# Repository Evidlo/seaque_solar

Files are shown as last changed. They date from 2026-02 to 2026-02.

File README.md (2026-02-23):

# seaque_solar

Design files for [SEAQUE](https://research.physics.illinois.edu/QI/Photonics/SEAQUE/) solar experiment.

# Files

- `board/` - KiCAD design files for IV sweeper
- `firmware/` - STM32 software for downlinking through SEAQUE
- `analysis/` - post-downlink analysis software

# Pics

Integrated experiment

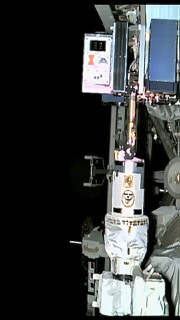
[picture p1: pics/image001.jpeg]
On-board the ISS






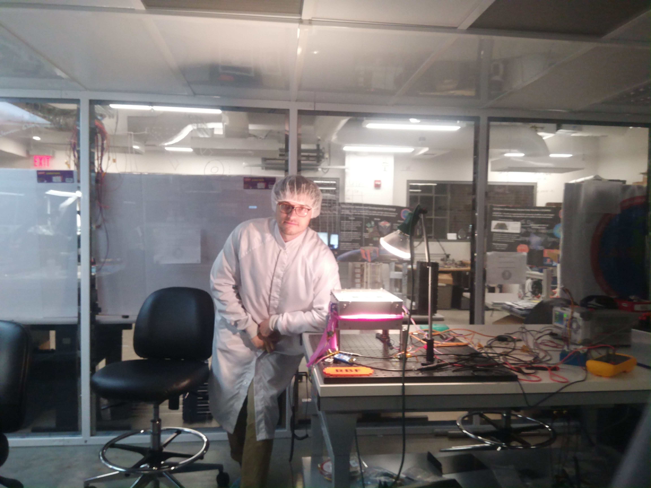
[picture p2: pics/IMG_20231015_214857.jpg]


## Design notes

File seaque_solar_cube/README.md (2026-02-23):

# SEAQUE QCB Firmware
This repo has the firmware for the SEAQUE Quantum Control Board, which controls a majority of experiment functions. It was originally an STM32CubeIDE project, but is now buildable with CMake via the `build.sh` script.

## How to Build
These instructions assume you are using a unix-like environment, like Linux, MacOS, or WSL. Fist make sure to install the GNU Arm Embedded Toolchain, as well as CMake. With these, the script `build.sh` should run without issue.

## How to Program/Debug
Install openocd, and in the main directory of the repo, run the command `openocd`. It should pick up the `openocd.cfg` file. There is also a `.gdbinit` file that connects to the openocd server, sets a source layout, and grabs symbols from the right file. To start debugging, simply run `arm-none-eabi-gdb`. To program the board, run the gdb command `load`.

target extended-remote :3333
lay src
focus cmd

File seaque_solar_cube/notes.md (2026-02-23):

# Programming

    ./build.sh && sh /home/evan/.arduino15/packages/STMicroelectronics/tools/STM32Tools/2.1.1/stm32CubeProg.sh 0 build/qcb.elf -g
	
# Debugging

program with gdb:
	load build/elf

connect with:
openocd

$ arm-none-eabi-gdb example.elf
then:
	target extended-remote localhost:3333

file build/qcb.elf
target extended-remote 10.195.192.196:3341
load

lay src
# reset and halt
mon reset halt
b main
c

b main
b [lineno]

# save to file
(gdb) set logging file large_array.txt
(gdb) set logging on
p packet_data[0]@3072

dump binary memory out.bin &packet_data[0] &packet_data[3072]

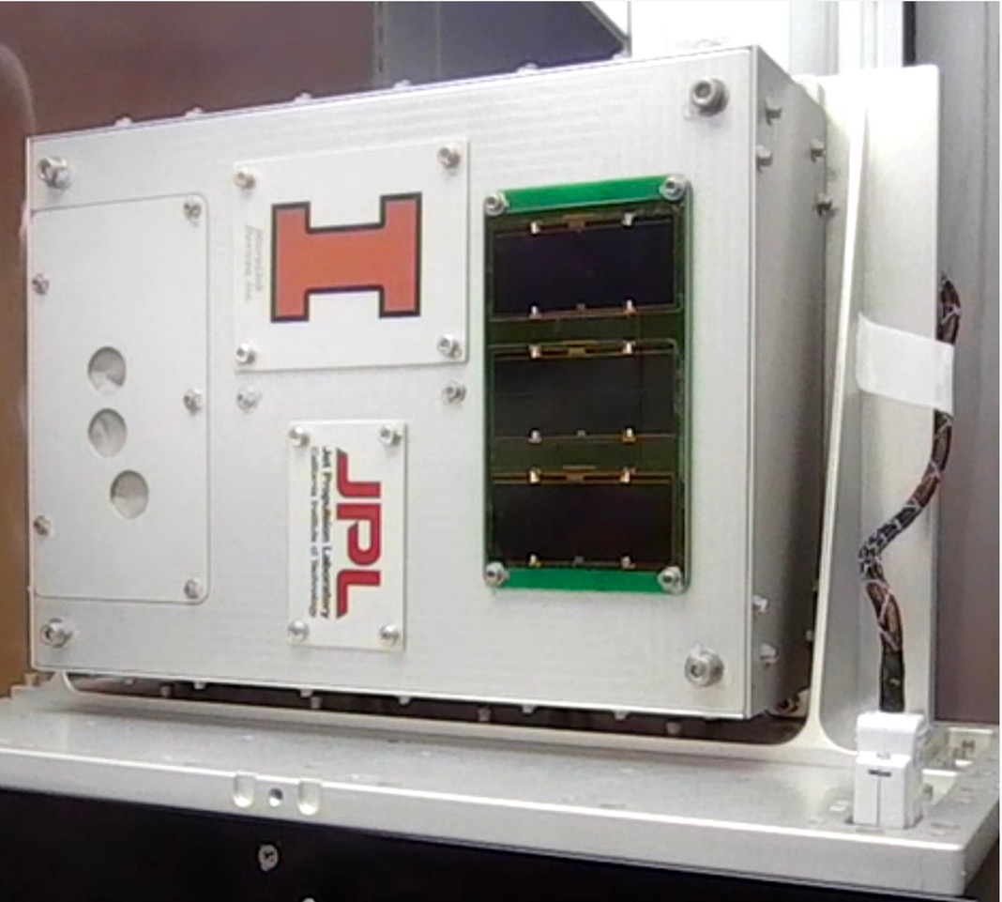
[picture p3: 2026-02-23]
pics/integration pic.jpeg

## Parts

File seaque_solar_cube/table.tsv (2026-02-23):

id | type | is_array | shape | readable | writeable | executable | read_cb | write_cb | exec_func | initial_value | include | comments
telemetry_en | bool | FALSE |  | TRUE | TRUE | FALSE |  |  |  | FALSE |  | Enable telemetry

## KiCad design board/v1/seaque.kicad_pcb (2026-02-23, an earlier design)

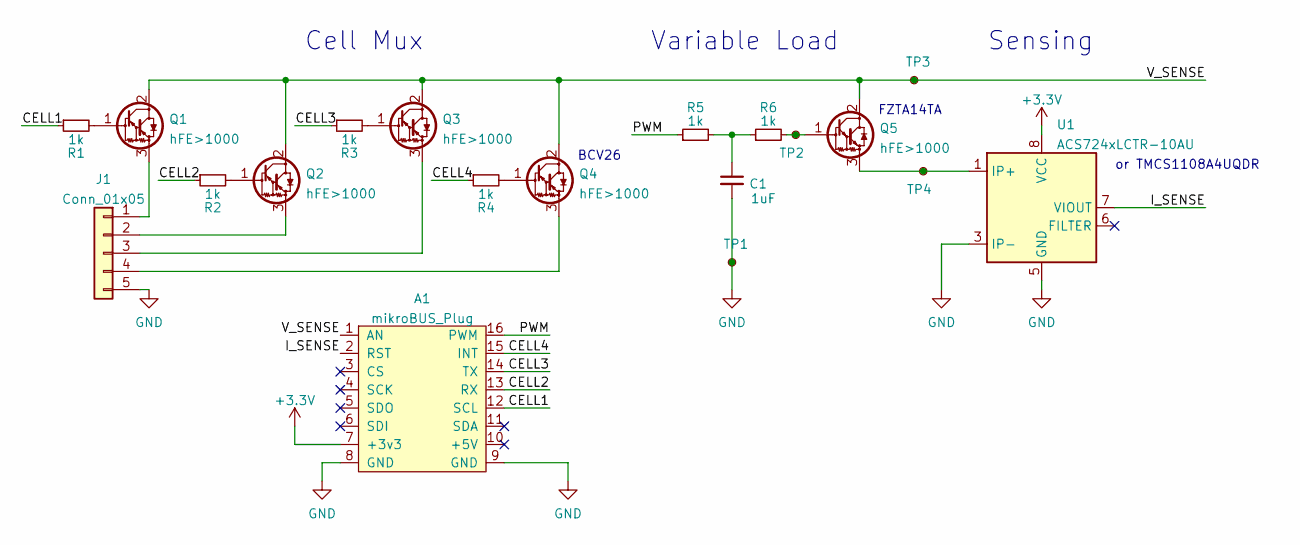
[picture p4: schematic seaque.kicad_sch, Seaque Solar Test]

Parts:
A1: mikroBUS_Plug
C1: 1uF; C_0603_1608Metric
J1: Conn_01x05; Molex_Pico-Lock_504050-0591_1x05-1MP_P1.50mm_Horizontal
Q1, Q2, Q3, Q4: hFE>1000; SC-59_Handsoldering
Q5: hFE>1000; SOT-223-3_TabPin2
R1, R2, R3, R4, R5, R6: 1k; R_0603_1608Metric
TP1, TP2, TP3, TP4: TestPoint_Small; TestPoint_Loop_D2.50mm_Drill1.0mm
U1: ACS724xLCTR-10AU; SOIC-8_3.9x4.9mm_P1.27mm

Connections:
+3V3: A1.7 (+3v3), U1.8 (VCC)
/CELL1: A1.12 (SCL), R1.1
/CELL2: A1.13 (RX), R2.1
/CELL3: A1.14 (TX), R3.1
/CELL4: A1.15 (INT), R4.1
/I_SENSE: A1.2 (RST), U1.7 (VIOUT)
/PWM: A1.16 (PWM), R5.1
/V_SENSE: A1.1 (AN), Q1.2 (C), Q2.2 (C), Q3.2 (C), Q4.2 (C), Q5.2 (C), TP3.1
GND: A1.8 (GND), A1.9 (GND), C1.2, J1.5, TP1.1, U1.3 (IP-), U1.4 (IP-), U1.5 (GND)
unnamed: C1.1, R5.2, R6.1
unnamed: J1.1, Q1.3 (E)
unnamed: J1.2, Q2.3 (E)
unnamed: J1.3, Q3.3 (E)
unnamed: J1.4, Q4.3 (E)
unnamed: Q1.1 (B), R1.2
unnamed: Q2.1 (B), R2.2
unnamed: Q3.1 (B), R3.2
unnamed: Q4.1 (B), R4.2
unnamed: Q5.1 (B), R6.2, TP2.1
unnamed: Q5.3 (E), TP4.1, U1.1 (IP+), U1.2 (IP+)

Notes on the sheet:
Cell Mux
or TMCS1108A4UQDR
Variable Load
BCV26
FZTA14TA
Sensing

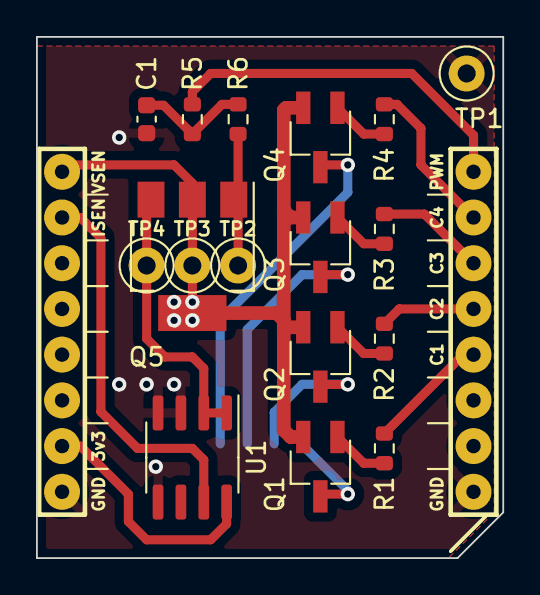
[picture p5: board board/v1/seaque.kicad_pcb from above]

Board: 2 copper layers, 25.9 x 29.0 mm, 19 parts (1 on the bottom side), 20 nets.

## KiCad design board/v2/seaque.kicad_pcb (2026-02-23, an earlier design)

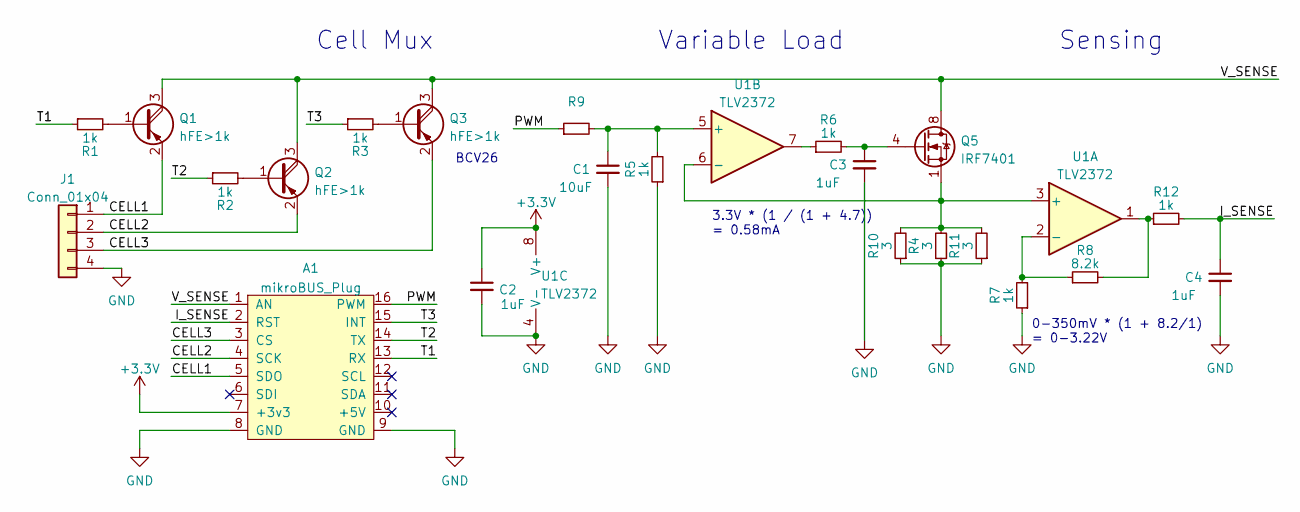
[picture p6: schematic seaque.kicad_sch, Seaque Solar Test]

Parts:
A1: mikroBUS_Plug
C1: 10uF; C_0603_1608Metric_Pad1.08x0.95mm_HandSolder
C2, C3, C4: 1uF; C_0603_1608Metric_Pad1.08x0.95mm_HandSolder
J1: Conn_01x04; Molex_Pico-Lock_504050-0491_1x04-1MP_P1.50mm_Horizontal
Q1, Q2, Q3: hFE>1k; SOT-23_Handsoldering
Q5: IRF7401; SOIC-8_3.9x4.9mm_P1.27mm
R1, R2, R3, R5, R6, R7, R12: 1k; C_0603_1608Metric_Pad1.08x0.95mm_HandSolder
R4, R10, R11: 3; C_0603_1608Metric_Pad1.08x0.95mm_HandSolder
R8: 8.2k; C_0603_1608Metric_Pad1.08x0.95mm_HandSolder
R9: C_0603_1608Metric_Pad1.08x0.95mm_HandSolder
U1: TLV2372; SOIC-8_3.9x4.9mm_P1.27mm

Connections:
+3V3: A1.7 (+3v3), C2.1, U1.8 (V+)
/CELL1: A1.5 (SDO), J1.1, Q1.2 (E)
/CELL2: A1.4 (SCK), J1.2, Q2.2 (E)
/CELL3: A1.3 (CS), J1.3, Q3.2 (E)
/I_SENSE: A1.2 (RST), C4.1, R12.2
/PWM: A1.16 (PWM), R9.1
/T1: A1.13 (RX), R1.1
/T2: A1.14 (TX), R2.1
/T3: A1.15 (INT), R3.1
/V_SENSE: A1.1 (AN), Q1.3 (C), Q2.3 (C), Q3.3 (C), Q5.5 (D), Q5.6 (D), Q5.7 (D), Q5.8 (D)
GND: A1.8 (GND), A1.9 (GND), C1.2, C2.2, C3.2, C4.2, J1.4, R4.1, R5.1, R7.1, R10.1, R11.1, U1.4 (V-)
unnamed: C1.1, R5.2, R9.2, U1.5 (+)
unnamed: C3.1, Q5.4 (G), R6.2
unnamed: Q1.1 (B), R1.2
unnamed: Q2.1 (B), R2.2
unnamed: Q3.1 (B), R3.2
unnamed: R6.1, U1.7
unnamed: R7.2, R8.1, U1.2 (-)
unnamed: R8.2, R12.1, U1.1
unnamed: Q5.1 (S), Q5.2 (S), Q5.3 (S), R4.2, R10.2, R11.2, U1.3 (+), U1.6 (-)

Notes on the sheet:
0-350mV * (1 + 8.2/1) = 0-3.22V
Cell Mux
Variable Load
BCV26
Sensing
3.3V * (1 / (1 + 4.7)) = 0.58mA

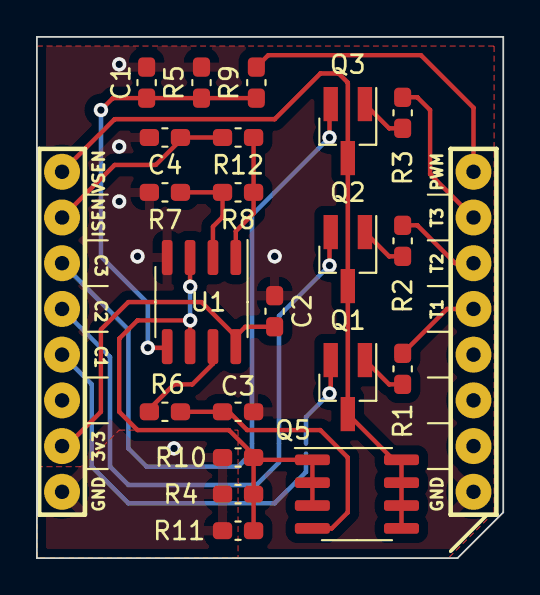
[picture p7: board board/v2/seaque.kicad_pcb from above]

Board: 2 copper layers, 25.9 x 29.0 mm, 23 parts (1 on the bottom side), 20 nets.

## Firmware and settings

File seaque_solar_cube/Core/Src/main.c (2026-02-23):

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
/* Includes ------------------------------------------------------------------*/
#include "main.h"

/* USER CODE BEGIN Includes */
#include <stdbool.h>
#include <string.h>
#include "axe_init.h"
/* USER CODE END Includes */

ADC_HandleTypeDef hadc1;
DMA_HandleTypeDef hdma_adc1;

FDCAN_HandleTypeDef hfdcan1;

TIM_HandleTypeDef htim1;
TIM_HandleTypeDef htim3;

UART_HandleTypeDef huart4;
UART_HandleTypeDef huart5;

/* USER CODE BEGIN PV */
uint8_t uart_char[MAX_SLIP_SIZE];
uint8_t pkt_buff[MAX_IPKT_SIZE];
uint8_t fdcan_tx_buff[64];
int fdcan_tx_buff_num = 0;
int transmit_buff_num = 0;
bool command_receive = false;
uint8_t can_rx_test[64];
FDCAN_TxHeaderTypeDef tx_header;
FDCAN_RxHeaderTypeDef rx_header;

const uint32_t my_address = (('Q' & 0x1F) << 24) + ('U' << 16) + ('E' << 8);
// The first multicast address is ALL, which is ASCII "ALL" preceeded by 1's over CAN.
const uint32_t all_address = (0x1F << 24) + ('A' << 16) + ('L' << 8) + 'L';
// The second multicast address is HALL, which is ASCII "ALL" preceeded by 0's over CAN.
// This makes HALL multicast messages higher priority.
const uint32_t hall_address = (0x00 << 24) + ('A' << 16) + ('L' << 8) + 'L';

// Other addresses
const uint32_t qcb_address = (('U' & 0x1F) << 24) + ('I' << 16) + ('U' << 8) + 'C';

const FDCAN_FilterTypeDef sFilterConfig1 = {
  .IdType = FDCAN_EXTENDED_ID,
  .FilterIndex = 0,
  .FilterType = FDCAN_FILTER_DUAL,
  .FilterConfig = FDCAN_FILTER_TO_RXFIFO0,
  .FilterID1 = PLSB_ADDR,
  .FilterID2 = PLSB_ADDR
};

const FDCAN_FilterTypeDef sFilterConfig2 = {
  .IdType = FDCAN_EXTENDED_ID,
  .FilterIndex = 1,
  .FilterType = FDCAN_FILTER_DUAL,
  .FilterConfig = FDCAN_FILTER_TO_RXFIFO0_HP,
  .FilterID1 = PLSB_ADDR,
  .FilterID2 = PLSB_ADDR
};

struct TNODE table[20];
volatile int adc_conv1_complete = 0;
#define NUM_CHANNELS 8
uint16_t adc_result[NUM_CHANNELS];
/* USER CODE END PV */

void SystemClock_Config(void);
static void MX_GPIO_Init(void);
static void MX_DMA_Init(void);
static void MX_ICACHE_Init(void);
static void MX_UART4_Init(void);
static void MX_UART5_Init(void);
static void MX_TIM3_Init(void);
static void MX_ADC1_Init(void);
static void MX_FDCAN1_Init(void);
static void MX_TIM1_Init(void);
/* USER CODE BEGIN PFP */
void send_stm32_uart(ipacket_t* pkt);
int axe_process_f(ipacket_t* pkt);
void takeMeasurement();
/* USER CODE END PFP */

/**
  * @brief  The application entry point.
  * @retval int
  */
int main(void)
{
  /* USER CODE BEGIN 1 */
  //char can_test[12] = "1234567890\r\n";
  /* USER CODE END 1 */

  /* MCU Configuration--------------------------------------------------------*/

  /* Reset of all peripherals, Initializes the Flash interface and the Systick. */
  HAL_Init();

  /* Configure the system clock */
  SystemClock_Config();

  /* Initialize all configured peripherals */
  MX_GPIO_Init();
  MX_DMA_Init();
  MX_ICACHE_Init();
  MX_UART4_Init();
  MX_UART5_Init();
  MX_TIM3_Init();
  MX_ADC1_Init();
  MX_FDCAN1_Init();
  MX_TIM1_Init();
  /* USER CODE BEGIN 2 */
  tx_header.Identifier = qcb_address;
  tx_header.IdType = FDCAN_EXTENDED_ID;
  tx_header.TxFrameType = FDCAN_DATA_FRAME;
  tx_header.DataLength = FDCAN_DLC_BYTES_64;
  tx_header.ErrorStateIndicator = FDCAN_ESI_ACTIVE;
  tx_header.BitRateSwitch = FDCAN_BRS_OFF;
  tx_header.FDFormat = FDCAN_FD_CAN;
  tx_header.MessageMarker = 0;
  tx_header.TxEventFifoControl = FDCAN_NO_TX_EVENTS;


  HAL_UART_Receive_IT(&huart4, uart_char, 1);
  memset(fdcan_tx_buff, '\0', sizeof(fdcan_tx_buff));

  // ICOMMs config
  iface_t can = {
      .active = true,
      // Should be all but your address if not RADCOM
      .addrs = {ALBIN_ADDR, DCM_ADDR, QCB_ADDR, GND_ADDR, RADCOM_ADDR},
      .mtu = CAN_MTU,
      .interface = CAN,
      .send_pkt = stm32can_send,
  };
  iface_table[0] = can;
  board_config.router = false;
  board_config.my_addr = PLSB_ADDR;
  board_config.crc32_f = crc32;
  board_config.axe_process_f = axe_process_f;
  seaque_fdcan = &hfdcan1;

  axe_config_t a_cfg = {
    .root_table = root_table,
    .root_table_len = TABLE_SIZE,
  };
  axe_set_config(a_cfg);
  init_axe();
  table_init();

  // PWM setup
  HAL_TIM_Base_Start(&htim3);
  HAL_TIM_PWM_Init(&htim3);
  HAL_TIM_PWM_Start(&htim3, TIM_CHANNEL_3);
  HAL_TIM_PWM_Start(&htim3, TIM_CHANNEL_2);
  HAL_TIM_PWM_Start(&htim3, TIM_CHANNEL_1);
  HAL_TIM_Base_Start(&htim1);
  HAL_TIM_PWM_Init(&htim1);
  HAL_TIM_PWM_Start(&htim1, TIM_CHANNEL_1);


  // ICOMM Packet
  ipacket_t pkt = {
    .cmd = 0,
    .addr_to = GND_ADDR,
    .addr_from = board_config.my_addr,
    .n = 0,
    .m = 0,
    .data = {'\0'},
  };

  // Serial debug variables
  int return_val = 0;
  char test[50] = {'\0'};

  int tempsize = snprintf(test, sizeof(test), "Started\r\n");
  HAL_UART_Transmit(&huart5, test, tempsize, 100);

  uint16_t* packet_data;
  packet_data = (uint16_t*)(pkt.data);
  /* USER CODE END 2 */

  /* Infinite loop */
  /* USER CODE BEGIN WHILE */
  while (1)
  {
    /* USER CODE END WHILE */

    /* USER CODE BEGIN 3 */

    // ----- Sweep Curve -----
    // MIKRO1_PWM
    for (int i=0; i<255; i++){
      htim3.Instance->CCR3 = i;
      takeMeasurement();
      packet_data[i] = adc_result[0];
      packet_data[i+256] = adc_result[1];
    }
    // MIKRO2_PWM
    for (int i=0; i<255; i++){
      htim1.Instance->CCR1 = i;
      takeMeasurement();
      packet_data[i+512] = adc_result[2];
      packet_data[i+512+256] = adc_result[3];
    }
    // MIKRO4_PWM
    for (int i=0; i<255; i++){
      htim3.Instance->CCR2 = i;
      takeMeasurement();
      packet_data[i+1024] = adc_result[6];
      packet_data[i+1024+256] = adc_result[7];
    }

    // a test packet
    /* for (int i=0;i<512 * 3 * 2;i++){ */
    /*   pkt.data[i] = i; */
    /* } */

    if (telemetry_en) {
      pkt.size = 512 * 3 * 2;
      send_ipacket(&pkt);
      comms_tick();
    }


    /* // send the whole packet over serial */
    /* HAL_UART_Transmit(&huart5, packet_data, pkt.size, 100); */
    /* HAL_Delay(100); */



    /* ----------------------------------- */
    /* uint16_t raw; */
    /* char msg[10]; */
    /* while (1) */
    /*   { */

    /*     // Get ADC value */
    /*     HAL_ADC_Start(&hadc1); */
    /*     HAL_ADC_PollForConversion(&hadc1, HAL_MAX_DELAY); */
    /*     raw = HAL_ADC_GetValue(&hadc1); */

    /*     // Convert to string and print */
    /*     sprintf(msg, "%hu\r\n", raw); */
    /*     HAL_UART_Transmit(&huart5, (uint8_t*)msg, strlen(msg), HAL_MAX_DELAY); */

    /*     // Pretend we have to do something else for a while */
    /*     HAL_Delay(1); */
    /*   } */
    /* ----------------------------------- */

    /* takeMeasurement(); */
    /* for (int i=0; i<NUM_CHANNELS; i++){ */
    /*     int tempsize = snprintf(test, sizeof(test), "RRank %d: %u\r\n", i+1, adc_result[i]); */
    /*     HAL_UART_Transmit(&huart5, test, tempsize, 100); */
    /*     HAL_Delay(10); */
    /* } */

    /* HAL_Delay(1000); */
    /* HAL_GPIO_WritePin(GPIOG, GPIO_PIN_1, GPIO_PIN_RESET); */
    /* HAL_Delay(1000); */
    /* HAL_GPIO_WritePin(GPIOG, GPIO_PIN_1, GPIO_PIN_SET); */
    /* HAL_Delay(300000); */

    HAL_Delay(300000);

  }
  /* USER CODE END 3 */
}

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
/* USER CODE BEGIN 4 */
size_t place = 0;
void HAL_UART_RxCpltCallback(UART_HandleTypeDef *huart)
{

  if (uart_char[place] == 0xC0){
    deslip_data(pkt_buff, uart_char);
    ipacket_t pkt = deserialize_ipacket(pkt_buff);
    recv_ipacket(&pkt);
    place = 0;
    HAL_UART_Receive_IT(&huart4, uart_char, 1);
  } else {
    place++;
    HAL_UART_Receive_IT(&huart4, uart_char + place, 1);
  }

}
/*
void HAL_FDCAN_RxFifo0Callback(FDCAN_HandleTypeDef *hfdcan, uint32_t RxFifo0ITs){
  HAL_FDCAN_GetRxMessage(&hfdcan1, FDCAN_RX_FIFO0, &rx_header, can_rx_test);
  //can_rx_test[64] = '\n';l
  HAL_UART_Transmit(&huart4, can_rx_test, strnlen(can_rx_test, 64), 100);

}*/
void HAL_FDCAN_RxFifo0Callback(FDCAN_HandleTypeDef *hfdcan, uint32_t RxFifo0ITs){
  do {
    FDCAN_RxHeaderTypeDef rxh = {0};
    uint8_t rx_buffer[64];
    HAL_FDCAN_GetRxMessage(&hfdcan1, FDCAN_RX_FIFO0, &rxh, rx_buffer);
    ipacket_t pkt = stm32can_deserialize_ipacket(&rxh, rx_buffer);
    recv_ipacket(&pkt);
  } while (HAL_FDCAN_GetRxFifoFillLevel(&hfdcan1, FDCAN_RX_FIFO0) > 0);
}
void send_stm32_uart(ipacket_t* pkt)
{
  uint8_t buff[MAX_IPKT_SIZE];
  uint8_t buffs[MAX_SLIP_SIZE];
  size_t data_len  = serialize_ipacket(pkt, buff);
  size_t sdata_len = slip_data(buffs, buff, data_len);
  HAL_UART_Transmit(&huart4, buffs, sdata_len, 100);

}

int axe_process_f(ipacket_t* pkt)
{
  ipacket_t rpkt = {
    .cmd = 0,
    .addr_to = pkt->addr_from,
    .addr_from = board_config.my_addr,
    .n = 0,
    .m = 0,
  };
  unsigned int reply_len = process_axe(pkt->data, pkt->size, rpkt.data, MAX_IPAYLOAD_SIZE);
  rpkt.size = reply_len;
  if (reply_len > 0 && reply_len < MAX_IPAYLOAD_SIZE){
    send_ipacket(&rpkt);
  }
  return 0;
}

int fputc(int ch, FILE *f)
{
    HAL_UART_Transmit(&huart5, (unsigned char *)&ch, 1, 100);
    return ch;
}

void takeMeasurement() {
    HAL_ADC_Start_DMA(&hadc1, (uint32_t*) adc_result, NUM_CHANNELS);
    while (adc_conv1_complete == 0);
    adc_conv1_complete = 0;
}

// Signal that ADC has finished conversions
void HAL_ADC_ConvCpltCallback(ADC_HandleTypeDef* AdcHandle){
  if (AdcHandle->Instance == ADC1)
    adc_conv1_complete = 1;
}

/* USER CODE END 4 */
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


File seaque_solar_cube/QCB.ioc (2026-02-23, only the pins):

Mcu.UserName=STM32L552ZETxQ
PA2.Signal=ADCx_IN7
PA3.Signal=ADCx_IN8
PA4.Signal=ADCx_IN9
PA5.Signal=ADCx_IN10
PA6.Signal=ADCx_IN11
PA7.Signal=ADCx_IN12
PB5.Signal=UART5_CTS
PB8.Signal=FDCAN1_RX
PB9.Signal=FDCAN1_TX
PC0.Signal=ADCx_IN1
PC1.Signal=ADCx_IN2
PC10.Signal=UART4_TX
PC11.Signal=UART4_RX
PC12.Signal=UART5_TX
PC7.GPIO_Label=MIKRO4_PWM
PC7.Signal=S_TIM3_CH2
PD2.Signal=UART5_RX
PE5.GPIO_Label=MIKRO1_PWM
PE5.Signal=S_TIM3_CH3
PE9.GPIO_Label=MIKRO2_PWM
PE9.Signal=S_TIM1_CH1
PG1.Signal=GPIO_Output

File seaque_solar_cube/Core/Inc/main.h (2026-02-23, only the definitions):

#define COMMAND_BUFFER_SIZE 64
#define MIKRO1_PWM_Pin GPIO_PIN_5
#define MIKRO1_PWM_GPIO_Port GPIOE
#define MIKRO2_PWM_Pin GPIO_PIN_9
#define MIKRO2_PWM_GPIO_Port GPIOE
#define MIKRO4_PWM_Pin GPIO_PIN_7
#define MIKRO4_PWM_GPIO_Port GPIOC

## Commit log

2022-02-22 updated MPPT board
    [seaque_mppt.kicad_pcb, seaque_mppt.kicad_sch]
2026-02-23 final commit
    [circuit.sch, seaque.kicad_pcb, seaque.kicad_sch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]
2026-02-23 reorganize data
    [ISS_11242024_12122024_1m.xlsx, QCB Debug Remote.cfg, circuit.sch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]

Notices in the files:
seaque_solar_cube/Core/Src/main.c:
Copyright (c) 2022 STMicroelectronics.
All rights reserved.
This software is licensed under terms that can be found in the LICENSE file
